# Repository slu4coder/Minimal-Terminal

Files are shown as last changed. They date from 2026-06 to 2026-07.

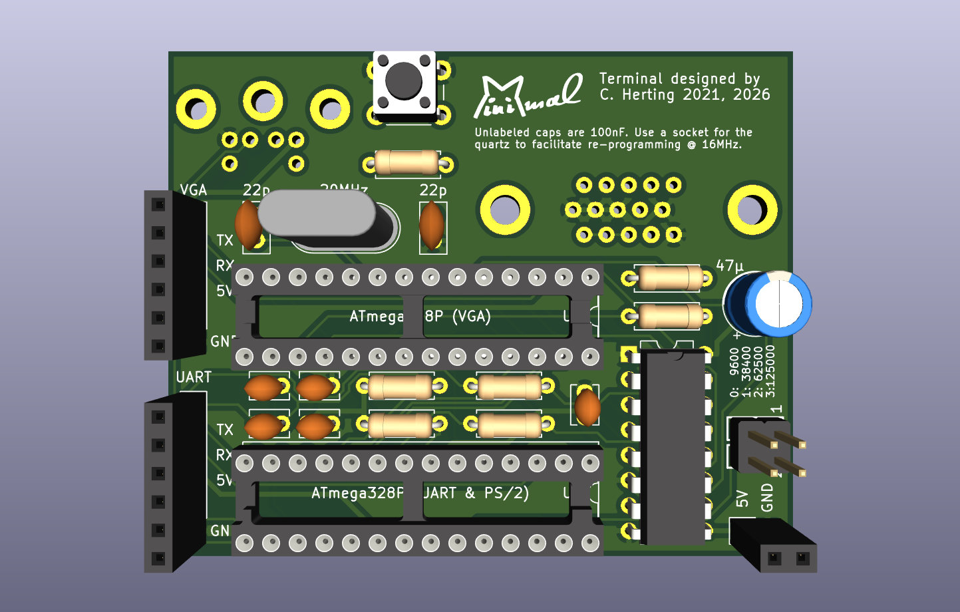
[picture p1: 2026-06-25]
Layout.jpg

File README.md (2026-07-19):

# Minimal Terminal 2026

This is my 'Minimal Serial UART Terminal' with a 50x30 character VGA display, PS2 keyboard readout (US, GER) and UART baudrates from 9600bps up to 500kbps. The design is based upon two ATmega328Ps and is described here: https://www.youtube.com/watch?v=jR-SqXLgBNo

grafik

This is a free and non-commercial project. I am in no way associated with any activies selling the 'Minimal Terminal' as a product. Any such activity represents a license violation. Individual licenses apply for hardware and software parts. Please refer to the applicable documentations for detailed licensing information. 

The Minimal Terminal is now ready to be used together with the 'Minimal UART Computer 3': https://github.com/slu4coder/Minimal-UART-Computer-3

Augusto Baffa has added support for US-international keyboard map: https://github.com/abaffa/Minimal-Terminal

I use a 20MHz crystal for a 50 x 30 characters display (default). In this setup, the following baudrates are possible: 500k, 250k, 230.4, 125k, 115.2k, 39: 62.5k, 57.6k, 38.4k,  28.8k, 19.2k, 9.6k

From these, I have imlemented the following four baudrates as "selectable via jumper":

grafik

Please note that per default the "1" and "2" values are pulled up, resulting in mode "3" or 125kbps. A jumper between GND and 5V *turns off* a value, respectively.

Optional (see source code for necessary modifications and baudrate possibilities):

o 16MHz crystal for a 40 x 30 characters display. 

o 24MHz crystal for a 60 x 30 characters display. Some users have reported that while older ICs
drive passive crystals at this frequency without problems, newer lots may need an active 24MHz oscillator.

See the Manual 'Minimal UART Computer 3', section 'Native Tool Chain / Terminal' for more information:
https://docs.google.com/document/d/1nIM-WRrVe7SzYY-DS1jcVHC4TCuIhlQ6LCHnZnEml7k/edit?usp=sharing

If you like this project and want to give something back, you can do so via PayPal. Thanks!

https://paypal.me/CarstenHerting

# Preparing the ATmega328 ICs

On a fresh ATmega328P, we set the low fuse byte from factory setting 0x62 (run on 8MHz internal oscillator) to
  
  ATmega328P ("I/O"): low fuse byte = 0xBF (use external oscillator, provide clock CLK0 on PB0)
  
  ATmega328P ("VGA"): low fuse byte = 0xF0 (use a provided external TTL clock)

1. Upload the sketch 'examples/ArduinoISP' into a spare Arduino Nano/Uno we’ll be using as a programmer.

2. Select 'Tools/Programmer/Arduino as ISP' (not ‘ArduinoISP’!).

On Windows: Open (or search for) the file: C:\Program Files (x86)\Arduino\hardware\arduino\avr\boards.txt

On Linux: Open (or search for) the file in a console with: sudo nano /usr/share/arduino/hardware/arduino/avr/boards.txt

3. We’ll hijack the configuration 'Arduino Nano' for our purpose:

Find the section: '## Arduino Nano w/ ATmega328P'. Change to: 'nano.menu.cpu.atmega328.bootloader.low_fuses=0xFF' and save the file (nano: Ctrl+O, Ctrl+X).

Close & reopen the Arduino IDE for the changes to become active.

Select target board: 'Arduino Nano', processor: 'AtMega328P'.

Connect the target's ISP to the programmer's ISP as shown below.

Select 'Tools/Burn bootloader' (takes ~5 seconds). Ignore errors for now. The fuse bytes are usually written as we’ve specified.

Upload the sketch into the TARGET with "Upload using Programmer", not the usual “Upload” or button.

Or use the serial upload connectors on the PCB with a breakout board if you've written a bootloader. Use a 16MHz crystal for programming.

PROGRAMMER (UNO/NANO)     TARGET (ATmega328P)

D13 (SCK) <-------------> Pin 19

D12 (MISO) <------------> Pin 18

D11 (MOSI) <------------> Pin 17

D10 (/RESET) <----------> Pin 1 <----- 10k ----> 5V

5V <--------------------> Pin 7

GND <-------------------> Pin 8

						  Pin 9 <----- 22p ----> GND

						  Pin 10 <---- 22p ----> GND

Pin 9/10: 16MHz crystal required for programming

o In case you write 0xF0 for external clock, the upload of the boot loader will not work,
	until you provide an external clock to IC pin 9.
  
o In case you write 0x62 the chip is running in factory setting (using its internal 8MHz oscillator at CPU clock 1MHz).

o In case you write 0xBF for CLK output on D8 (PB0, IC pin 14) verify with an LED and resistor.

o You can also upload a sketch into the ATmega328P with 'Sketch/Upload Using Programmer'.

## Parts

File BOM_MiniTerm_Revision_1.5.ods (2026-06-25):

Item | Qty | Reference(s) | Value | LibPart | Footprint
1 | 2 | C1, C2 | .1µ | Device:C_Small | Capacitor_THT:C_Disc_D3.8mm_W2.6mm_P2.50mm
2 | 1 | C3 | 47µ | Device:CP | Capacitor_THT:CP_Radial_D6.3mm_P2.50mm
3 | 3 | C4, C9, C10 | .1µ | Device:C | Capacitor_THT:C_Disc_D3.8mm_W2.6mm_P2.50mm
4 | 2 | C5, C7 | 22p | Device:C_Small | Capacitor_THT:C_Disc_D5.0mm_W2.5mm_P2.50mm
5 | 1 | J1 | UART | Connector:Conn_01x06_Female | Connector_PinSocket_2.54mm:PinSocket_1x06_P2.54mm_Vertical
6 | 1 | J2 | PS/2 Keyboard | Connector:Mini-DIN-6 | ArduinoPC:FP_MINI_DIN_6_PS2
7 | 1 | J3 | VGA DB15 HD Connector (Female) | Connector:DB15_Female_HighDensity | ArduinoPC:VGA DSUB15HD_female
8 | 1 | J4 | 5V | Connector:Conn_01x02_Female | Connector_PinSocket_2.54mm:PinSocket_1x02_P2.54mm_Vertical
9 | 1 | J5 | VGA | Connector:Conn_01x06_Female | Connector_PinSocket_2.54mm:PinSocket_1x06_P2.54mm_Vertical
10 | 1 | J6 | SPEED | Connector_Generic:Conn_02x02_Top_Bottom | ArduinoPC:PinHeader_2x02_P2.54mm_Vertical_Jumper
11 | 2 | R1, R2 | 1k | Device:R | Resistor_THT:R_Axial_DIN0207_L6.3mm_D2.5mm_P7.62mm_Horizontal
12 | 2 | R3, R4 | 10k | Device:R | Resistor_THT:R_Axial_DIN0207_L6.3mm_D2.5mm_P7.62mm_Horizontal
13 | 1 | R5 | 150 | Device:R | Resistor_THT:R_Axial_DIN0207_L6.3mm_D2.5mm_P7.62mm_Horizontal
14 | 2 | R6, R7 | 75 | Device:R | Resistor_THT:R_Axial_DIN0207_L6.3mm_D2.5mm_P7.62mm_Horizontal
15 | 1 | SW1 | SW_Push | Switch:SW_Push | Button_Switch_THT:SW_PUSH_6mm
16 | 1 | U1 | 74HC166 | ArduinoPC:74HC166 | Package_DIP:DIP-16_W7.62mm
17 | 1 | U2 | ATmega328P (VGA) | ArduinoPC:ATmega328P-PU | Package_DIP:DIP-28_W7.62mm_Socket
18 | 1 | U3 | ATmega328P (UART & PS/2) | ArduinoPC:ATmega328P-PU | Package_DIP:DIP-28_W7.62mm_Socket
19 | 1 | Y1 | 20MHz | Device:Crystal_Small | Crystal:Crystal_HC18-U_Vertical
20 | 2 |  |  | Jumper

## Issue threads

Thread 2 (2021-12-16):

Full Swing Crystal Oscillator on 24Mhz

abaffa, 2021-12-16:
Hi ,
your solution is really nice! Are you using full external clock to generate 24mhz? I could not make it work on 24mhz using the atmega oscillator circuit :(

Best,
Augusto Baffa

abaffa, 2021-12-31:
I modified to use an active oscillator for 24mhz and it's working well... also I changed the ps/2 scancodes to us-international keyboard map... check my improvements at https://github.com/abaffa/Minimal-Terminal :)

Closed 2021-12-31.

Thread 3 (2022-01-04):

80 x 25 again... but now based on Grant Searle's solution

abaffa, 2022-01-04:
Hi,
  I'm trying to port the Grant Searle's solution to your project but I'll need some time to understand the assembly code. Maybe it's more familiar to you and can help to improve the terminal http://searle.x10host.com/MonitorKeyboard/index.html

Grant Searle's projects are very popular and probably you already saw that... but it's interesting how he could generate 80x25 chars ntsc B&W with 16mhz clock. The project is quite similiar to urs (using 74x166 to serialize the video signal) and two atmegas (atmega88 to uart/ps2).

I've compared the connections from both projects and I guess it's easy to adapt the video generation code - All code is asm and compiled using Avr Studio 7 so that's how he got more processing capacity.

best regards and happy new year \o/

Augusto Baffa

Closed 2022-02-22.

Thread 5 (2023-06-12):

Uart chip inactive without keyboard attached

MRjimbob81, 2023-06-12:
Hello,

Looks like the UART/PS2 processor is in a constant wait state (or crashed) if no keyboard is attached to the PS2 port on initial startup.
This will not allow any UART traffic to pass through to the VGA processor to be displayed on screen. eg: a keyboard-less terminal.

slu4coder, 2023-06-21:
Hi,
I cannot confirm or reproduce this behavior on my hardware. Powering up the terminal without PS/2 keyboard attached leaves my Minimal Terminal running just fine and displaying received characters.

MRjimbob81, 2023-06-22:
Looks like this issue was my own stupidity. I burn'ed a forked image to the UART/PS2 processor and not the original one. Both files have the same file name...

My apologies.

Closed 2023-06-22.

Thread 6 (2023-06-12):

Uart processor drives Tx line hard blocking serial traffic

MRjimbob81, 2023-06-12:
Not a bug per say - just an observation.

The UART/PS2 processor drives the Tx line constantly at such a level that it overpowers any other Tx data on that line.
An example would be where an upstream MCU receives serial input from the PS2 keyboard, PC serial output and/or output from another serial device.

Maybe making the Tx output hi-Z when not transmitting would allow other traffic to pass through.

slu4coder, 2023-06-21:
Thanks for pointing this out. Since I am using the standard Arduino functions 'Serial.begin', 'Serial.print' etc. for this, I'd rather keep the code simple as it is. Feel free to experiment with fiddling around with the data direction register of the Arduino in between sending stuff to adapt for your needs.

Closed 2023-06-21.

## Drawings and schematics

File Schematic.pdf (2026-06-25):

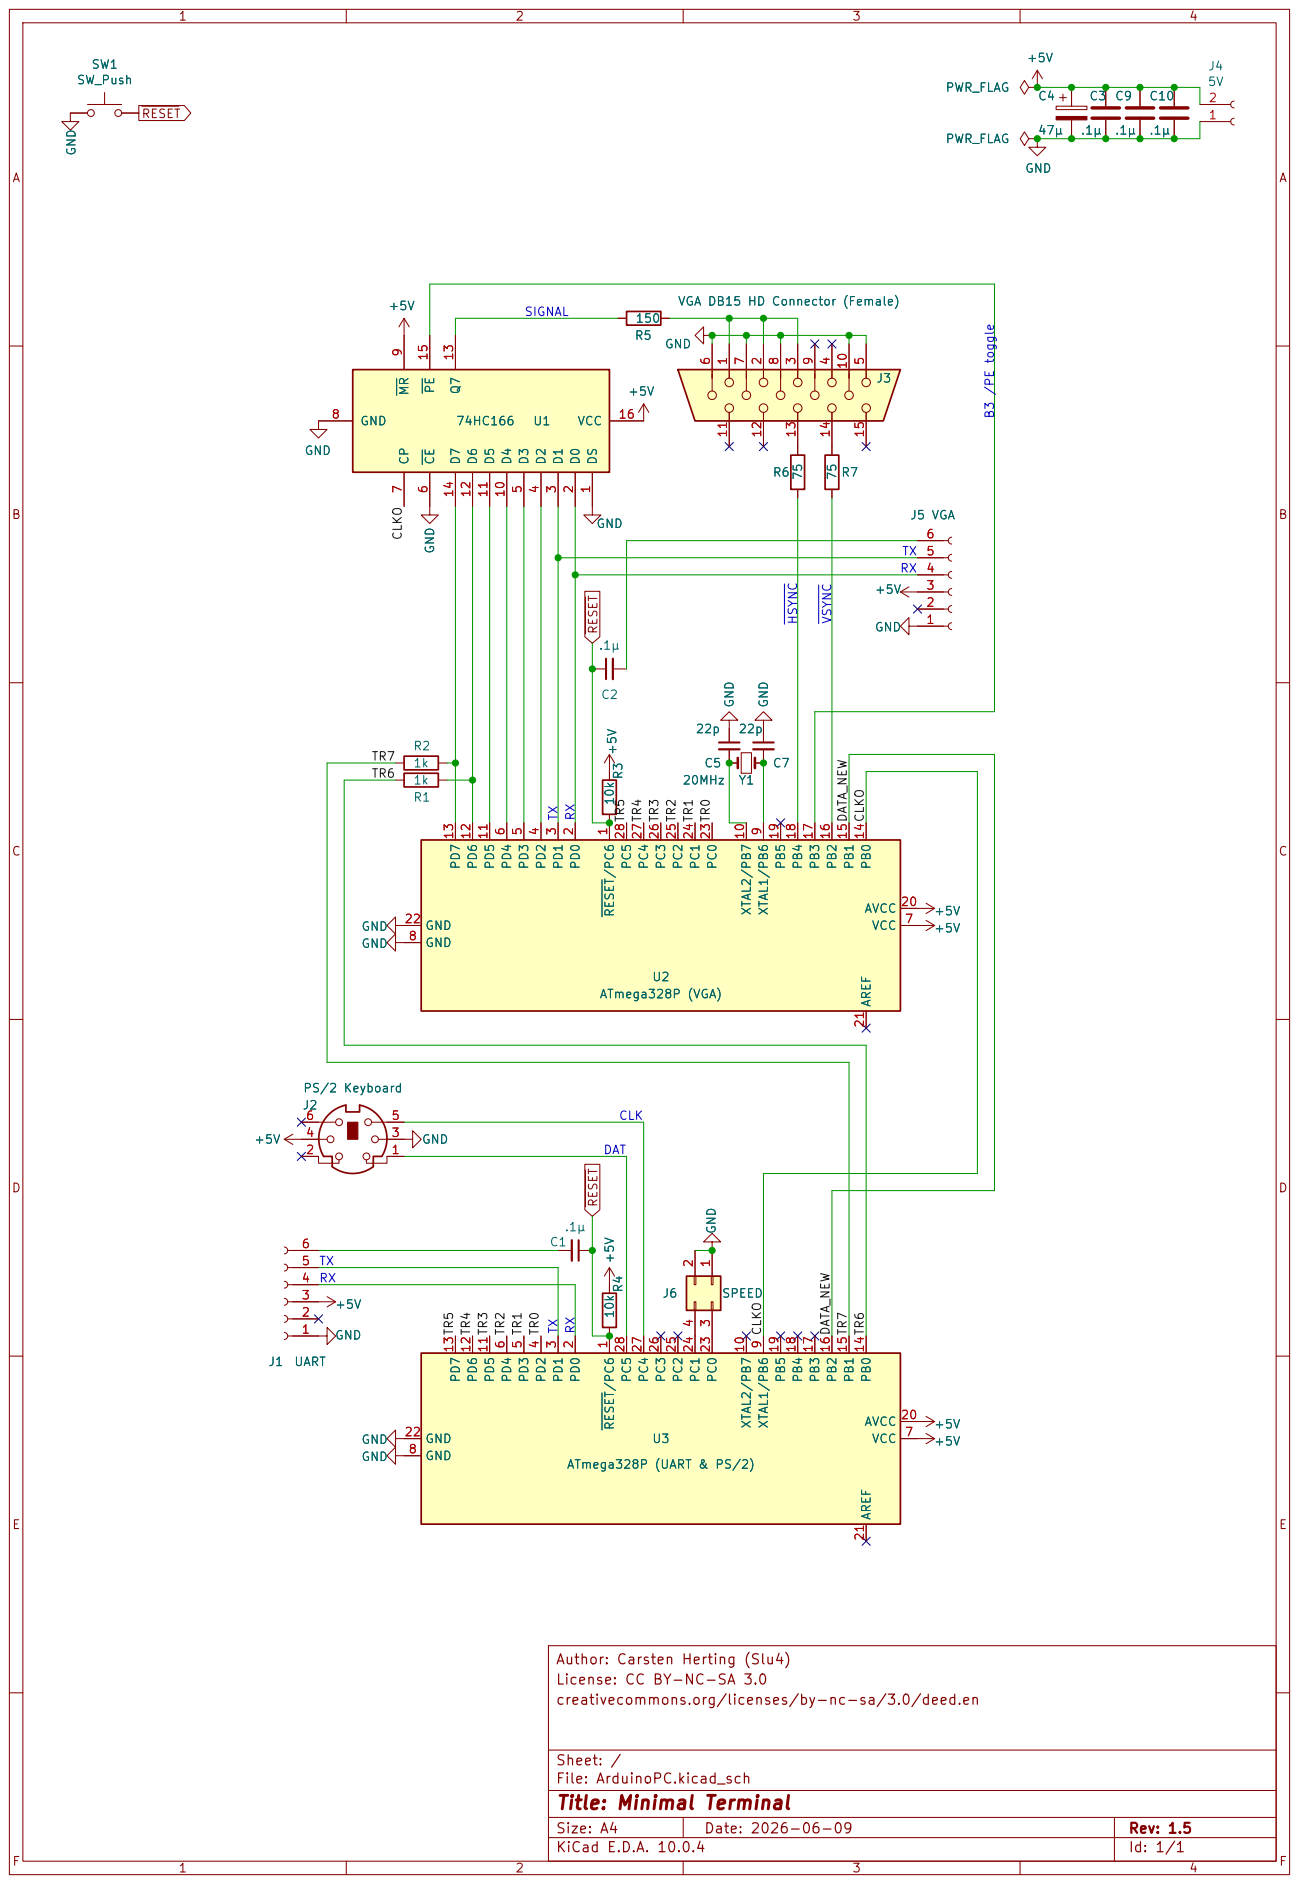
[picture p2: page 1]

VGA DB15 HD Connector (Female)

VGA DB15 HD Connector (Female) 6

License: CC BY-NC-SA 3.0
creativecommons.org/licenses/by-nc-sa/3.0/deed.en

Size: A4 | Rev: 1.5
KiCad E.D.A. 10.0.4 | Id: 1/1 | F Date: 2026-06-09

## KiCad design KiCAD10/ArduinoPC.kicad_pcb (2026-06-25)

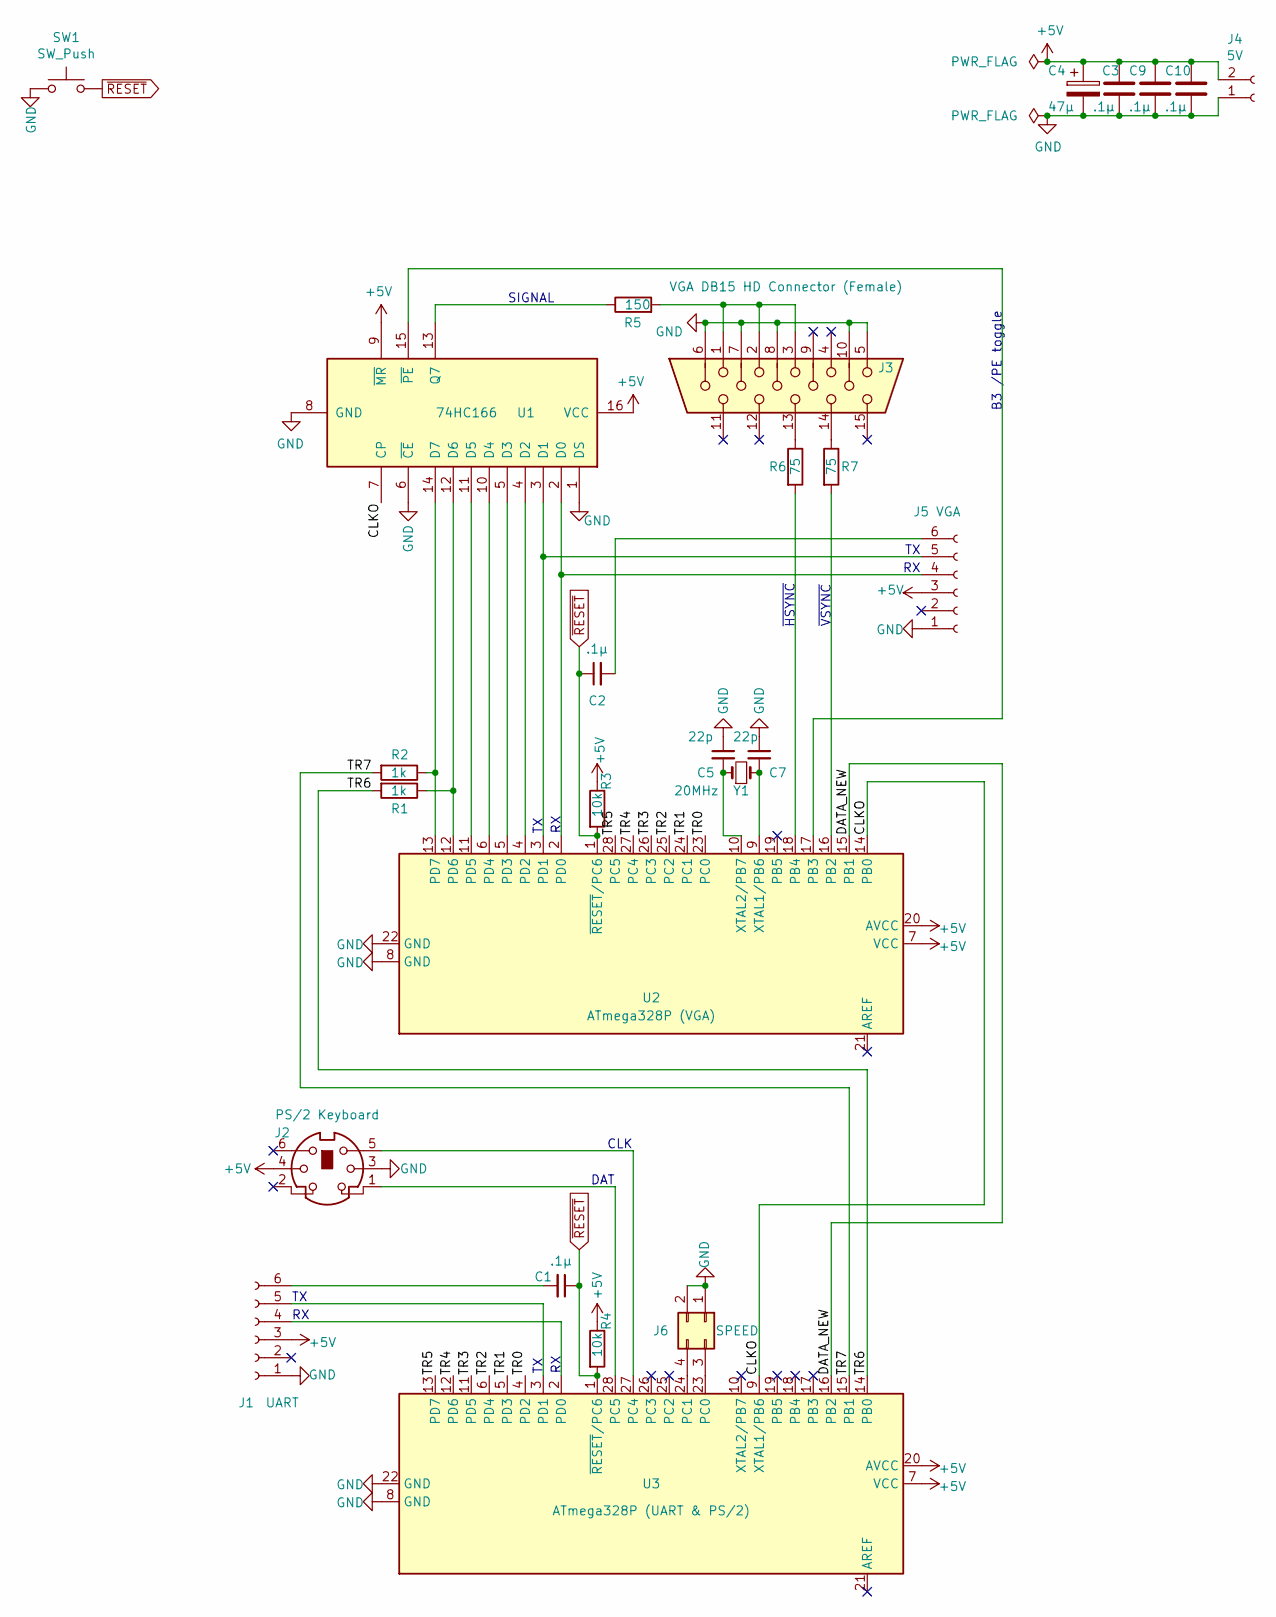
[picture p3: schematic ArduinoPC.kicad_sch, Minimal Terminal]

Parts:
C1, C2, C4, C9, C10: .1µ; C_Disc_D3.8mm_W2.6mm_P2.50mm
C3: 47µ; CP_Radial_D6.3mm_P2.50mm
C5, C7: 22p; C_Disc_D5.0mm_W2.5mm_P2.50mm
J1: UART; PinSocket_1x06_P2.54mm_Vertical
J2: PS/2 Keyboard; FP_MINI_DIN_6_PS2
J3: VGA DB15 HD Connector (Female); VGA DSUB15HD_female
J4: 5V; PinSocket_1x02_P2.54mm_Vertical
J5: VGA; PinSocket_1x06_P2.54mm_Vertical
J6: SPEED; PinHeader_2x02_P2.54mm_Vertical_Jumper
R1, R2: 1k; R_Axial_DIN0207_L6.3mm_D2.5mm_P7.62mm_Horizontal
R3, R4: 10k; R_Axial_DIN0207_L6.3mm_D2.5mm_P7.62mm_Horizontal
R5: 150; R_Axial_DIN0207_L6.3mm_D2.5mm_P7.62mm_Horizontal
R6, R7: 75; R_Axial_DIN0207_L6.3mm_D2.5mm_P7.62mm_Horizontal
SW1: SW_Push; SW_PUSH_6mm
U1: 74HC166; DIP-16_W7.62mm
U2: ATmega328P (VGA); DIP-28_W7.62mm_Socket
U3: ATmega328P (UART & PS/2); DIP-28_W7.62mm_Socket
Y1: 20MHz; Crystal_HC18-U_Vertical

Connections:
+5V: C3.1, C4.1, C9.1, C10.1, J1.3, J2.4, J4.2, J5.3, R3.1, R4.1, U1.9 (~MR), U1.16 (VCC), U2.7 (VCC), U2.20 (AVCC), U3.7 (VCC), U3.20 (AVCC)
/CLKO: U1.7 (CP), U2.14 (PB0), U3.9 (XTAL1/PB6)
/DATA_NEW: U2.15 (PB1), U3.16 (PB2)
/TR0: U2.23 (PC0), U3.4 (PD2)
/TR1: U2.24 (PC1), U3.5 (PD3)
/TR2: U2.25 (PC2), U3.6 (PD4)
/TR3: U2.26 (PC3), U3.11 (PD5)
/TR4: U2.27 (PC4), U3.12 (PD6)
/TR5: U2.28 (PC5), U3.13 (PD7)
/TR6: R1.2, U3.14 (PB0)
/TR7: R2.2, U3.15 (PB1)
GND: C3.2, C4.2, C5.1, C7.1, C9.2, C10.2, J1.1, J2.3, J3.5, J3.6, J3.7, J3.8, J3.10, J4.1, J5.1, J6.1, J6.2, SW1.1, U1.1 (DS), U1.6 (~CE), U1.8 (GND), U2.8 (GND), U2.22 (GND), U3.8 (GND), U3.22 (GND)
unnamed: C1.2, J1.6
unnamed: C2.2, J5.6
unnamed: C5.2, U2.10 (XTAL2/PB7), Y1.1
unnamed: C7.2, U2.9 (XTAL1/PB6), Y1.2
unnamed: J1.4, U3.2 (PD0)
unnamed: J1.5, U3.3 (PD1)
unnamed: J2.1, U3.28 (PC5)
unnamed: J2.5, U3.27 (PC4)
unnamed: J3.1, J3.2, J3.3, R5.2
unnamed: J3.13, R6.1
unnamed: J3.14, R7.1
unnamed: J5.4, U1.2 (D0), U2.2 (PD0)
unnamed: J5.5, U1.3 (D1), U2.3 (PD1)
unnamed: J6.3, U3.23 (PC0)
unnamed: J6.4, U3.24 (PC1)
unnamed: R1.1, U1.12 (D6), U2.12 (PD6)
unnamed: R2.1, U1.14 (D7), U2.13 (PD7)
unnamed: R5.1, U1.13 (Q7)
unnamed: R6.2, U2.18 (PB4)
unnamed: R7.2, U2.16 (PB2)
unnamed: U1.4 (D2), U2.4 (PD2)
unnamed: U1.5 (D3), U2.5 (PD3)
unnamed: U1.10 (D4), U2.6 (PD4)
unnamed: U1.11 (D5), U2.11 (PD5)
unnamed: U1.15 (~PE), U2.17 (PB3)
~RESET: C1.1, C2.1, R3.2, R4.2, SW1.2, U2.1 (~RESET/PC6), U3.1 (~RESET/PC6)

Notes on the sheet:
CLK
SIGNAL
B3 /PE toggle
~{VSYNC}
~{HSYNC}
DAT

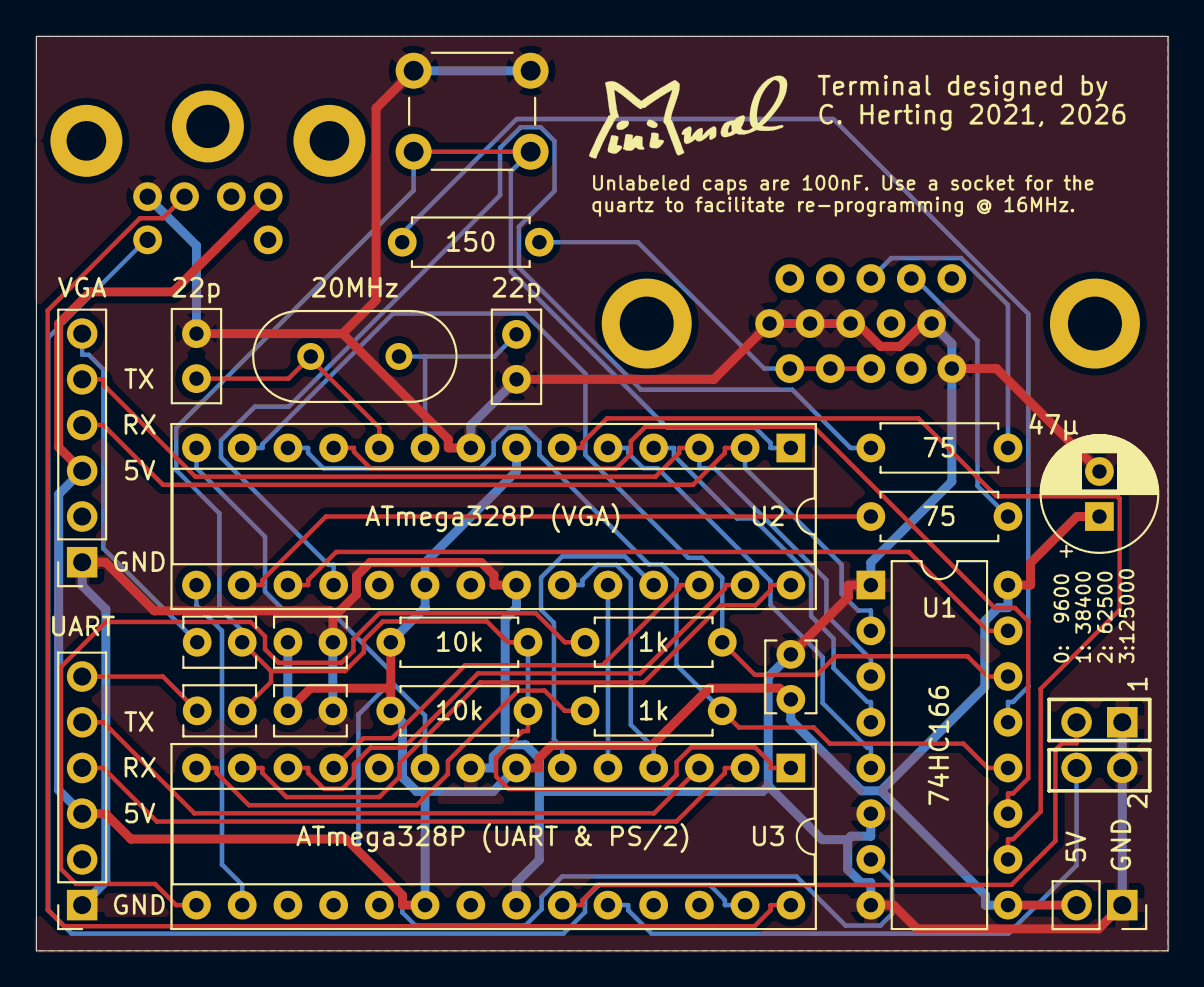
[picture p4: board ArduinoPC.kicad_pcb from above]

Board: 2 copper layers, 62.9 x 50.8 mm, 26 parts (0 on the bottom side), 38 nets.

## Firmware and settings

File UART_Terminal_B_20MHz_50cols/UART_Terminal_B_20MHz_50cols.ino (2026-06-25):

// ***************************************************************************
// *****                                                                 *****
// ***** AtMega328P UART ANSI Terminal with 50x30 Character VGA and PS/2 *****
// *****                                                                 *****
// *****        written by Carsten Herting 16.08.2025 Version 2.3        *****
// *****                                                                 *****
// ***************************************************************************
// Set AtMega328P FuseA from 0xFF to 0xBF to output system clock CLKO on PB0
// Pin C0-5: terminal input bits 0-5
// Pin D0-7: parallel pixel output to 74166, in between: D6-7 terminal input bits 6-7
// Pin B0:   CLKO ATmega328 system clock output (program fuse byte to 0xBF)
// Pin B1:   DATA_NEW input handshake
// Pin B2:   /VSYNC VGA (timer1, every 1/60s, could also be done)
// Pin B3:   /PE low pulse (by hand inside ISR for 74166 /PE pixel shift register sync parallel load)
// Pin B4:   /HSYNC VGA (by hand inside ISR, every 32µs)
// Pin B5:   DATA_ACK output handshake
// See license at the end of this file.

#define WIDTH     50              // 20MHz crystal required
#define HEIGHT    30

char row = 0, col = 0;            // current cursor position in terminal window
char hideCursor = 0;              // cursor can be switched off by CSI
volatile int vline = 0;           // current vertical position of pixel video output
volatile byte vram[HEIGHT][WIDTH];// array of VideoRAM
volatile char start = 0;          // start line of the VideoRAM (thus avoiding moving data while scrolling)
volatile int frames = 0;          // 1/60s frame counter for cursor blinking
volatile byte regout = 0;         // index of current output position in queue
volatile byte regin = 0;          // index of current input position in queue
volatile byte reg[256];           // ring buffer data of keyboard input register

const volatile byte __attribute__ ((aligned (256))) charset[8][256] PROGMEM =
{
  0x00,0x00,0x00,0x00,0x00,0x00,0x00,0x00,0x00,0x00,0x00,0x00,0x00,0x00,0x00,0x00,0x00,0x00,0x00,0x00,0x00,0x00,0x00,0x00,0x00,0x00,0x00,0x00,0x00,0x00,0x03,0xC0,0x00,0x18,0x66,0x66,0x18,0x62,0x3C,0x06,0x0C,0x30,0x00,0x00,0x00,0x00,0x00,0x00,0x3C,0x18,0x3C,0x3C,0x06,0x7E,0x3C,0x7E,0x3C,0x3C,0x00,0x00,0x0E,0x00,0x70,0x3C,0x3C,0x18,0x7C,0x3C,0x78,0x7E,0x7E,0x3C,0x66,0x3C,0x1E,0x66,0x60,0x63,0x66,0x3C,0x7C,0x3C,0x7C,0x3C,0x7E,0x66,0x66,0x63,0x66,0x66,0x7E,0x3C,0x00,0x3C,0x00,0x00,0x3C,0x00,0x00,0x00,0x00,0x00,0x00,0x00,0x00,0x00,0x00,0x00,0x00,0x00,0x00,0x00,0x00,0x00,0x00,0x00,0x00,0x00,0x00,0x00,0x00,0x00,0x00,0x0E,0x18,0x70,0x00,0x00,0x00,0x00,0x00,0x18,0x18,0x18,0x18,0x18,0x18,0x00,0x00,0x00,0x18,0x18,0xFF,0xFF,0x01,0x80,0x0F,0xF0,0xFF,0x00,0x0F,0xF0,0xFF,0x00,0x0F,0xF0,0xFF,0x00,0x0F,0xF0,0xFF,0xE7,0x99,0x99,0xE7,0x9D,0xC3,0xF9,0xF3,0xCF,0xFF,0xFF,0xFF,0xFF,0xFF,0xFF,0xC3,0xE7,0xC3,0xC3,0xF9,0x81,0xC3,0x81,0xC3,0xC3,0xFF,0xFF,0xF1,0xFF,0x8F,0xC3,0xC3,0xE7,0x83,0xC3,0x87,0x81,0x81,0xC3,0x99,0xC3,0xE1,0x99,0x9F,0x9C,0x99,0xC3,0x83,0xC3,0x83,0xC3,0x81,0x99,0x99,0x9C,0x99,0x99,0x81,0xC3,0xFF,0xC3,0xFF,0xFF,0xC3,0xFF,0xFF,0xFF,0xFF,0xFF,0xFF,0xFF,0xFF,0xFF,0xFF,0xFF,0xFF,0xFF,0xFF,0xFF,0xFF,0xFF,0xFF,0xFF,0xFF,0xFF,0xFF,0xFF,0xFF,0xFF,0xFF,0xF1,0xE7,0x8F,0xFF,0xFF,
  0x00,0x00,0x00,0x00,0x00,0x00,0x00,0x00,0x00,0x00,0x00,0x00,0x00,0x00,0x00,0x00,0x00,0x00,0x00,0x00,0x00,0x00,0x00,0x00,0x00,0x00,0x00,0x00,0x00,0x00,0x07,0xE0,0x00,0x18,0x66,0x66,0x3E,0x66,0x66,0x0C,0x18,0x18,0x66,0x18,0x00,0x00,0x00,0x03,0x66,0x18,0x66,0x66,0x0E,0x60,0x66,0x66,0x66,0x66,0x00,0x00,0x18,0x00,0x18,0x66,0x66,0x3C,0x66,0x66,0x6C,0x60,0x60,0x66,0x66,0x18,0x0C,0x6C,0x60,0x77,0x76,0x66,0x66,0x66,0x66,0x66,0x18,0x66,0x66,0x63,0x66,0x66,0x06,0x30,0x60,0x0C,0x18,0x00,0x66,0x00,0x60,0x00,0x06,0x00,0x0E,0x00,0x60,0x18,0x06,0x60,0x38,0x00,0x00,0x00,0x00,0x00,0x00,0x00,0x18,0x00,0x00,0x00,0x00,0x00,0x00,0x18,0x18,0x18,0x00,0x10,0x00,0x00,0x00,0x18,0x18,0x18,0x18,0x18,0x18,0x00,0x00,0x00,0x18,0x18,0x7F,0xFE,0x03,0xC0,0x0F,0xF0,0xFF,0x00,0x0F,0xF0,0xFF,0x00,0x0F,0xF0,0xFF,0x00,0x0F,0xF0,0xFF,0xE7,0x99,0x99,0xC1,0x99,0x99,0xF3,0xE7,0xE7,0x99,0xE7,0xFF,0xFF,0xFF,0xFC,0x99,0xE7,0x99,0x99,0xF1,0x9F,0x99,0x99,0x99,0x99,0xFF,0xFF,0xE7,0xFF,0xE7,0x99,0x99,0xC3,0x99,0x99,0x93,0x9F,0x9F,0x99,0x99,0xE7,0xF3,0x93,0x9F,0x88,0x89,0x99,0x99,0x99,0x99,0x99,0xE7,0x99,0x99,0x9C,0x99,0x99,0xF9,0xCF,0x9F,0xF3,0xE7,0xFF,0x99,0xFF,0x9F,0xFF,0xF9,0xFF,0xF1,0xFF,0x9F,0xE7,0xF9,0x9F,0xC7,0xFF,0xFF,0xFF,0xFF,0xFF,0xFF,0xFF,0xE7,0xFF,0xFF,0xFF,0xFF,0xFF,0xFF,0xE7,0xE7,0xE7,0xFF,0xEF,
  0x00,0x00,0x00,0x00,0x00,0x00,0x00,0x00,0x00,0x00,0x00,0x00,0x00,0x00,0x00,0x00,0x00,0x00,0x00,0x00,0x00,0x00,0x00,0x00,0x00,0x00,0x00,0x00,0x00,0x00,0x0E,0x70,0x00,0x18,0x66,0xFF,0x60,0x0C,0x3C,0x18,0x30,0x0C,0x3C,0x18,0x00,0x00,0x00,0x06,0x6E,0x38,0x06,0x06,0x1E,0x7C,0x60,0x0C,0x66,0x66,0x18,0x18,0x30,0x7E,0x0C,0x06,0x6E,0x66,0x66,0x60,0x66,0x60,0x60,0x60,0x66,0x18,0x0C,0x78,0x60,0x7F,0x7E,0x66,0x66,0x66,0x66,0x60,0x18,0x66,0x66,0x63,0x3C,0x66,0x0C,0x30,0x30,0x0C,0x3C,0x00,0x6E,0x3C,0x60,0x3C,0x06,0x3C,0x18,0x3E,0x60,0x00,0x00,0x60,0x18,0x66,0x7C,0x3C,0x7C,0x3E,0x7C,0x3E,0x7E,0x66,0x66,0x63,0x66,0x66,0x7E,0x18,0x18,0x18,0x00,0x30,0x00,0x00,0x00,0x18,0x18,0x18,0x18,0x18,0x18,0x00,0x00,0x00,0x1C,0x38,0x3F,0xFC,0x07,0xE0,0x0F,0xF0,0xFF,0x00,0x0F,0xF0,0xFF,0x00,0x0F,0xF0,0xFF,0x00,0x0F,0xF0,0xFF,0xE7,0x99,0x00,0x9F,0xF3,0xC3,0xE7,0xCF,0xF3,0xC3,0xE7,0xFF,0xFF,0xFF,0xF9,0x91,0xC7,0xF9,0xF9,0xE1,0x83,0x9F,0xF3,0x99,0x99,0xE7,0xE7,0xCF,0x81,0xF3,0xF9,0x91,0x99,0x99,0x9F,0x99,0x9F,0x9F,0x9F,0x99,0xE7,0xF3,0x87,0x9F,0x80,0x81,0x99,0x99,0x99,0x99,0x9F,0xE7,0x99,0x99,0x9C,0xC3,0x99,0xF3,0xCF,0xCF,0xF3,0xC3,0xFF,0x91,0xC3,0x9F,0xC3,0xF9,0xC3,0xE7,0xC1,0x9F,0xFF,0xFF,0x9F,0xE7,0x99,0x83,0xC3,0x83,0xC1,0x83,0xC1,0x81,0x99,0x99,0x9C,0x99,0x99,0x81,0xE7,0xE7,0xE7,0xFF,0xCF,
  0x00,0x00,0x00,0x00,0x00,0x00,0x00,0x00,0x00,0x00,0x00,0x00,0x00,0x00,0x00,0x00,0x00,0x00,0x00,0x00,0x00,0x00,0x00,0x00,0x00,0x00,0x00,0x00,0x00,0x00,0x1C,0x38,0x00,0x18,0x00,0x66,0x3C,0x18,0x38,0x00,0x30,0x0C,0xFF,0x7E,0x00,0x7E,0x00,0x0C,0x76,0x18,0x0C,0x1C,0x66,0x06,0x7C,0x18,0x3C,0x3E,0x00,0x00,0x60,0x00,0x06,0x0C,0x6E,0x7E,0x7C,0x60,0x66,0x78,0x78,0x6E,0x7E,0x18,0x0C,0x70,0x60,0x6B,0x7E,0x66,0x7C,0x66,0x7C,0x3C,0x18,0x66,0x66,0x6B,0x18,0x3C,0x18,0x30,0x18,0x0C,0x7E,0x00,0x6E,0x06,0x7C,0x60,0x3E,0x66,0x3E,0x66,0x7C,0x38,0x06,0x6C,0x18,0x7F,0x66,0x66,0x66,0x66,0x66,0x60,0x18,0x66,0x66,0x6B,0x3C,0x66,0x0C,0x70,0x18,0x0E,0x3B,0x7F,0x1F,0xFF,0xF8,0x1F,0xFF,0xF8,0x1F,0xFF,0xF8,0xFF,0x07,0xE0,0x0F,0xF0,0x1F,0xF8,0x0F,0xF0,0x0F,0xF0,0xFF,0x00,0x0F,0xF0,0xFF,0x00,0x0F,0xF0,0xFF,0x00,0x0F,0xF0,0xFF,0xE7,0xFF,0x99,0xC3,0xE7,0xC7,0xFF,0xCF,0xF3,0x00,0x81,0xFF,0x81,0xFF,0xF3,0x89,0xE7,0xF3,0xE3,0x99,0xF9,0x83,0xE7,0xC3,0xC1,0xFF,0xFF,0x9F,0xFF,0xF9,0xF3,0x91,0x81,0x83,0x9F,0x99,0x87,0x87,0x91,0x81,0xE7,0xF3,0x8F,0x9F,0x94,0x81,0x99,0x83,0x99,0x83,0xC3,0xE7,0x99,0x99,0x94,0xE7,0xC3,0xE7,0xCF,0xE7,0xF3,0x81,0xFF,0x91,0xF9,0x83,0x9F,0xC1,0x99,0xC1,0x99,0x83,0xC7,0xF9,0x93,0xE7,0x80,0x99,0x99,0x99,0x99,0x99,0x9F,0xE7,0x99,0x99,0x94,0xC3,0x99,0xF3,0x8F,0xE7,0xF1,0xC4,0x80,
  0x00,0x00,0x00,0x00,0x00,0x00,0x00,0x00,0x00,0x00,0x00,0x00,0x00,0x00,0x00,0x00,0x00,0x00,0x00,0x00,0x00,0x00,0x00,0x00,0x00,0x00,0x00,0x00,0x00,0x00,0x38,0x1C,0x00,0x00,0x00,0xFF,0x06,0x30,0x67,0x00,0x30,0x0C,0x3C,0x18,0x00,0x00,0x00,0x18,0x66,0x18,0x30,0x06,0x7F,0x06,0x66,0x18,0x66,0x06,0x00,0x00,0x30,0x7E,0x0C,0x18,0x60,0x66,0x66,0x60,0x66,0x60,0x60,0x66,0x66,0x18,0x0C,0x78,0x60,0x63,0x6E,0x66,0x60,0x66,0x78,0x06,0x18,0x66,0x66,0x7F,0x3C,0x18,0x30,0x30,0x0C,0x0C,0x18,0x00,0x60,0x3E,0x66,0x60,0x66,0x7E,0x18,0x66,0x66,0x18,0x06,0x78,0x18,0x7F,0x66,0x66,0x66,0x66,0x60,0x3C,0x18,0x66,0x66,0x7F,0x18,0x66,0x18,0x18,0x18,0x18,0x6E,0x7F,0x1F,0xFF,0xF8,0x1F,0xFF,0xF8,0x1F,0xFF,0xF8,0xFF,0x0F,0xF0,0x07,0xE0,0x0F,0xF0,0x1F,0xF8,0x00,0x00,0x00,0x0F,0x0F,0x0F,0x0F,0xF0,0xF0,0xF0,0xF0,0xFF,0xFF,0xFF,0xFF,0xFF,0xFF,0x00,0xF9,0xCF,0x98,0xFF,0xCF,0xF3,0xC3,0xE7,0xFF,0xFF,0xFF,0xE7,0x99,0xE7,0xCF,0xF9,0x80,0xF9,0x99,0xE7,0x99,0xF9,0xFF,0xFF,0xCF,0x81,0xF3,0xE7,0x9F,0x99,0x99,0x9F,0x99,0x9F,0x9F,0x99,0x99,0xE7,0xF3,0x87,0x9F,0x9C,0x91,0x99,0x9F,0x99,0x87,0xF9,0xE7,0x99,0x99,0x80,0xC3,0xE7,0xCF,0xCF,0xF3,0xF3,0xE7,0xFF,0x9F,0xC1,0x99,0x9F,0x99,0x81,0xE7,0x99,0x99,0xE7,0xF9,0x87,0xE7,0x80,0x99,0x99,0x99,0x99,0x9F,0xC3,0xE7,0x99,0x99,0x80,0xE7,0x99,0xE7,0xE7,0xE7,0xE7,0x91,0x80,
  0x00,0x00,0x00,0x00,0x00,0x00,0x00,0x00,0x00,0x00,0x00,0x00,0x00,0x00,0x00,0x00,0x00,0x00,0x00,0x00,0x00,0x00,0x00,0x00,0x00,0x00,0x00,0x00,0x00,0x00,0x70,0x0E,0x00,0x00,0x00,0x66,0x7C,0x66,0x66,0x00,0x18,0x18,0x66,0x18,0x18,0x00,0x18,0x30,0x66,0x18,0x60,0x66,0x06,0x66,0x66,0x18,0x66,0x66,0x18,0x18,0x18,0x00,0x18,0x00,0x66,0x66,0x66,0x66,0x6C,0x60,0x60,0x66,0x66,0x18,0x6C,0x6C,0x60,0x63,0x66,0x66,0x60,0x3C,0x6C,0x66,0x18,0x66,0x3C,0x77,0x66,0x18,0x60,0x30,0x06,0x0C,0x18,0x00,0x66,0x66,0x66,0x60,0x66,0x60,0x18,0x3E,0x66,0x18,0x06,0x6C,0x18,0x6B,0x66,0x66,0x7C,0x3E,0x60,0x06,0x18,0x66,0x3C,0x3E,0x3C,0x3E,0x30,0x18,0x18,0x18,0x00,0x30,0x18,0x18,0x18,0x18,0x18,0x18,0x00,0x00,0x00,0x00,0x1C,0x38,0x00,0x00,0x07,0xE0,0x3F,0xFC,0x00,0x00,0x00,0x0F,0x0F,0x0F,0x0F,0xF0,0xF0,0xF0,0xF0,0xFF,0xFF,0xFF,0xFF,0xFF,0xFF,0x99,0x83,0x99,0x99,0xFF,0xE7,0xE7,0x99,0xE7,0xE7,0xFF,0xE7,0xCF,0x99,0xE7,0x9F,0x99,0xF9,0x99,0x99,0xE7,0x99,0x99,0xE7,0xE7,0xE7,0xFF,0xE7,0xFF,0x99,0x99,0x99,0x99,0x93,0x9F,0x9F,0x99,0x99,0xE7,0x93,0x93,0x9F,0x9C,0x99,0x99,0x9F,0xC3,0x93,0x99,0xE7,0x99,0xC3,0x88,0x99,0xE7,0x9F,0xCF,0xF9,0xF3,0xE7,0xFF,0x99,0x99,0x99,0x9F,0x99,0x9F,0xE7,0xC1,0x99,0xE7,0xF9,0x93,0xE7,0x94,0x99,0x99,0x83,0xC1,0x9F,0xF9,0xE7,0x99,0xC3,0xC1,0xC3,0xC1,0xCF,0xE7,0xE7,0xE7,0xFF,0xCF,
  0x00,0x00,0x00,0x00,0x00,0x00,0x00,0x00,0x00,0x00,0x00,0x00,0x00,0x00,0x00,0x00,0x00,0x00,0x00,0x00,0x00,0x00,0x00,0x00,0x00,0x00,0x00,0x00,0x00,0x00,0xE0,0x07,0x00,0x18,0x00,0x66,0x18,0x46,0x3F,0x00,0x0C,0x30,0x00,0x00,0x18,0x00,0x18,0x60,0x3C,0x7E,0x7E,0x3C,0x06,0x3C,0x3C,0x18,0x3C,0x3C,0x00,0x18,0x0E,0x00,0x70,0x18,0x3C,0x66,0x7C,0x3C,0x78,0x7E,0x60,0x3C,0x66,0x3C,0x38,0x66,0x7E,0x63,0x66,0x3C,0x60,0x0E,0x66,0x3C,0x18,0x3C,0x18,0x63,0x66,0x18,0x7E,0x3C,0x03,0x3C,0x18,0xFF,0x3C,0x3E,0x7C,0x3C,0x3E,0x3C,0x18,0x06,0x66,0x3C,0x06,0x66,0x3C,0x63,0x66,0x3C,0x60,0x06,0x60,0x7C,0x0E,0x3E,0x18,0x36,0x66,0x0C,0x7E,0x0E,0x18,0x70,0x00,0x10,0x18,0x18,0x18,0x18,0x18,0x18,0x00,0x00,0x00,0x00,0x18,0x18,0x00,0x00,0x03,0xC0,0x7F,0xFE,0x00,0x00,0x00,0x0F,0x0F,0x0F,0x0F,0xF0,0xF0,0xF0,0xF0,0xFF,0xFF,0xFF,0xFF,0xE7,0xFF,0x99,0xE7,0xB9,0xC0,0xFF,0xF3,0xCF,0xFF,0xFF,0xE7,0xFF,0xE7,0x9F,0xC3,0x81,0x81,0xC3,0xF9,0xC3,0xC3,0xE7,0xC3,0xC3,0xFF,0xE7,0xF1,0xFF,0x8F,0xE7,0xC3,0x99,0x83,0xC3,0x87,0x81,0x9F,0xC3,0x99,0xC3,0xC7,0x99,0x81,0x9C,0x99,0xC3,0x9F,0xF1,0x99,0xC3,0xE7,0xC3,0xE7,0x9C,0x99,0xE7,0x81,0xC3,0xFC,0xC3,0xE7,0x00,0xC3,0xC1,0x83,0xC3,0xC1,0xC3,0xE7,0xF9,0x99,0xC3,0xF9,0x99,0xC3,0x9C,0x99,0xC3,0x9F,0xF9,0x9F,0x83,0xF1,0xC1,0xE7,0xC9,0x99,0xF3,0x81,0xF1,0xE7,0x8F,0xFF,0xEF,
  0x00,0x00,0x00,0x00,0x00,0x00,0x00,0x00,0x00,0x00,0x00,0x00,0x00,0x00,0x00,0x00,0x00,0x00,0x00,0x00,0x00,0x00,0x00,0x00,0x00,0x00,0x00,0x00,0x00,0x00,0xC0,0x03,0x00,0x00,0x00,0x00,0x00,0x00,0x00,0x00,0x00,0x00,0x00,0x00,0x30,0x00,0x00,0x00,0x00,0x00,0x00,0x00,0x00,0x00,0x00,0x00,0x00,0x00,0x00,0x30,0x00,0x00,0x00,0x00,0x00,0x00,0x00,0x00,0x00,0x00,0x00,0x00,0x00,0x00,0x00,0x00,0x00,0x00,0x00,0x00,0x00,0x00,0x00,0x00,0x00,0x00,0x00,0x00,0x00,0x00,0x00,0x00,0x00,0x00,0x18,0xFF,0x00,0x00,0x00,0x00,0x00,0x00,0x00,0x7C,0x00,0x00,0x3C,0x00,0x00,0x00,0x00,0x00,0x60,0x06,0x00,0x00,0x00,0x00,0x00,0x00,0x00,0x78,0x00,0x00,0x18,0x00,0x00,0x00,0x18,0x18,0x18,0x18,0x18,0x18,0x00,0x00,0x00,0x00,0x18,0x18,0x00,0x00,0x01,0x80,0xFF,0xFF,0x00,0x00,0x00,0x0F,0x0F,0x0F,0x0F,0xF0,0xF0,0xF0,0xF0,0xFF,0xFF,0xFF,0xFF,0xFF,0xFF,0xFF,0xFF,0xFF,0xFF,0xFF,0xFF,0xFF,0xFF,0xFF,0xCF,0xFF,0xFF,0xFF,0xFF,0xFF,0xFF,0xFF,0xFF,0xFF,0xFF,0xFF,0xFF,0xFF,0xFF,0xCF,0xFF,0xFF,0xFF,0xFF,0xFF,0xFF,0xFF,0xFF,0xFF,0xFF,0xFF,0xFF,0xFF,0xFF,0xFF,0xFF,0xFF,0xFF,0xFF,0xFF,0xFF,0xFF,0xFF,0xFF,0xFF,0xFF,0xFF,0xFF,0xFF,0xFF,0xFF,0xFF,0xFF,0xFF,0xE7,0x00,0xFF,0xFF,0xFF,0xFF,0xFF,0xFF,0xFF,0x83,0xFF,0xFF,0xC3,0xFF,0xFF,0xFF,0xFF,0xFF,0x9F,0xF9,0xFF,0xFF,0xFF,0xFF,0xFF,0xFF,0xFF,0x87,0xFF,0xFF,0xE7,0xFF,0xFF,0xFF,
};

void setup()
{
  noInterrupts();                   // disable interrupts before messing around with timer registers

  DDRC  = 0b00000000;               // PORTC is always input
  PORTC = 0b00000000;
  DDRD  = 0b11111111;               // PORTD is always output
  PORTD = 0b00000000;
  DDRB  = 0b00111100;               // B0-1: terminal input bits 0-1, B2: VSYNC (timer1), B3: 74165 /PL (timer2 or by hand???), B4: HSync by hand inside ISR
  PORTB = 0b00011000;               // HSYNC=1, /PE=1

  GTCCR = 0b10000011;               // set TSM, PSRSYNC und PSRASY to correlate all 3 timers

  // *****************************
  // ***** Timer0: VGA HSYNC *****
  // *****************************
  TCNT0  = 36;                       // align VSYNC and HSYNC pulses
  TCCR0A = (1 << WGM01) | (0 << WGM00);   // mode 2: Clear Timer on Compare Match (CTC)
  TCCR0B = (0 << WGM02) | (0 << CS02) | (1 << CS01) | (0 << CS00); // x8 prescaler -> 0.5µs
  OCR0A  = 79;                      // 60cols (24MHz): 95, 50cols (20MHz): 79, 40cols (16MHz): 63, compare match register A (TOP) -> 32µs
  TIMSK0 = (1 << OCIE0A);           // output Compare Match A Interrupt Enable (not working: TOIE1 with ISR TIMER0_TOIE1_vect because it is already defined by timing functions)

  // *****************************
  // ***** Timer1: VGA VSYNC *****
  // *****************************
  TCNT1  = 0;
  TCCR1A = (1 << COM1B1) | (1 << COM1B0) | (1 << WGM11) | (1 << WGM10); // mode 15 (Fast PWM), set OC1B on Compare Match, clear OC1B at BOTTOM, controlling OC1B pin 10
  TCCR1B = (1 << WGM13) | (1 << WGM12) | (1 << CS12) | (0 << CS11) | (1 << CS10); // x 1024 prescaler -> 64µs
  OCR1A  = 324;                     // 60cols (24MHz): 389, 50cols (20MHz): 324, 40cols (16MHz): 259, compare match register A (TOP) -> 16.64ms
  OCR1B  = 0;                       // compare match register B -> 64µs
  TIMSK1 = (1 << TOIE1);            // enable timer overflow interrupt setting vlines = 0

  // ************************************************
  // ***** Timer2: only used for jitter control *****
  // ************************************************
  TCNT2  = 0;
  TCCR2A = (0<<COM2A1) | (0<<COM2A0) | (1<<WGM21) | (1<<WGM20); // mode 7: Fast PWM, COM2A0=0: normal port HIGH, COM2A0=1: Toggle OC2A pin 11 on Compare Match
  TCCR2B = (1<<WGM22) | (0<<CS22) | (0<<CS21) | (1<<CS20) ;     // set x0 prescaler -> 62.5ns;
  OCR2A  = 7;                       // compare match register A (TOP) -> 250ns
  TIMSK2 = 0;                       // no interrupts here

  GTCCR = 0;                        // clear TSM => all timers start synchronously
  interrupts();

  UCSR0B = 0;                       // brute-force the USART off just in case...

  for (int j=0; j<HEIGHT; j++) for (int i=0; i<WIDTH; i++) vram[j][i] = ' ';
}

void loop()
{  
  if ((frames & 63) == 32 && col < WIDTH && hideCursor == 0) vram[row][col] |= 0b10000000;
  else if ((frames & 63) == 0 && col < WIDTH) vram[row][col] &= 0b01111111;

  if (regout != regin)                            // was a character received
  {
    if (col < WIDTH) vram[row][col] &= 0b01111111; // restore character beneath the cursor BEFORE a possible scrolling happens
    do ProcessChar(reg[regout++]); while (regout != regin); // process the character
  }
}

int main() { setup(); while (true) loop(); }      // enforce main() loop w/o serial handler

ISR(TIMER1_OVF_vect) { vline = 0; frames++; }     // timer1 overflow interrupt resets vline at HSYNC
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

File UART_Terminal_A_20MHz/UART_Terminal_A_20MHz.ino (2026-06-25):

/**************************************************************************************
  *****                                                                           *****
  ***** ATmega328P UART & PS/2 Terminal Interface written by Carsten Herting 2021 *****
  *****                 Version 2.3 (original release: 02.06.2021)                *****
  ***** 21.08.2025: Added more baudrate options for 24/20/16MHz crystals          *****
  ***** 25.06.2026: Use default 20MHz crystal for use with Minimal UART CPU 3     *****
  *****                                                                           *****                                                                           
  *************************************************************************************
  This Atmega328P reads serial data from it's UART RX and transfers it to the 2nd
  ATmega328P handling VGA. PS/2 data is converted into ASCII and sent via UART TX.
  Set the fuse byte from 0xFF to 0xF0 to use an external TTL clock (provided by B).
  C0-C3: UART SPEED SCALER
  C4: PS/2 clock input, triggers a pin change interrupt
  C5: PS/2 dtat input, sampled at the rising edge of the PS/2 clock
  D0,1: UART RX, TX
  D2-7: bits 0-5 of transfer output to C0-5
  B0,1: bits 6-7 of transfer output to D6-7 via 1k resistors
  B2: DATA_NEW output to B0 input of 2nd µC
  See license at the end of this file.
*/

volatile byte ps2_scan = 0; // holds valid PS/2 scancode (set this to 0 after processing!)

const byte LookupScanToASCII[4 * 128] PROGMEM = // lookup table (in: PS/2 scancode, out: ASCII code)
{ 
/*
  0,0,0,0,0,0,0,0,          0,0,0,0,0,0,94,0,           0,0,0,0,0,113,49,0,         0,0,121,115,97,119,50,0,     // plain key
  0,99,120,100,101,52,51,0, 0,32,118,102,116,114,53,0,  0,110,98,104,103,122,54,0,  0,0,109,106,117,55,56,0,
  0,44,107,105,111,48,57,0, 0,46,45,108,0,112,0,0,      0,0,0,0,0,96,0,0,           0,0,10,43,0,35,0,0,
  0,60,0,0,0,0,8,0,         0,0,0,0,0,0,0,0,            0,127,0,0,0,0,27,0,         0,0,0,0,0,0,0,0,
  
  0,0,0,0,0,0,0,0,          0,0,0,0,0,0,248,0,          0,0,0,0,0,81,33,0,          0,0,89,83,65,87,34,0,        // with SHIFT
  0,67,88,68,69,36,0,0,     0,0,86,70,84,82,37,0,       0,78,66,72,71,90,38,0,      0,0,77,74,85,47,40,0,
  0,59,75,73,79,61,41,0,    0,58,95,76,0,80,63,0,       0,0,0,0,0,0,0,0,            0,0,0,42,0,39,0,0,
  0,62,0,0,0,0,0,0,         0,0,0,0,0,0,0,0,            0,0,0,0,0,0,0,0,            0,0,0,0,0,0,0,0,
  
  0,0,0,0,0,0,0,0,          0,0,0,0,0,0,0,0,            0,0,0,0,0,64,0,0,           0,0,0,0,0,0,0,0,             // with ALT(GR)
  0,0,0,0,0,0,0,0,          0,0,0,0,0,0,0,0,            0,0,0,0,0,0,0,0,            0,0,0,0,0,123,91,0,
  0,0,0,0,0,125,93,0,       0,0,0,0,0,0,92,0,           0,0,0,0,0,0,0,0,            0,0,0,126,0,0,0,0,
  0,124,0,0,0,0,0,0,        0,0,0,0,0,0,0,0,            0,0,0,0,0,0,0,0,            0,0,0,0,0,0,0,0,
  
  0,0,0,0,0,0,0,0,          0,0,0,0,0,0,0,0,            0,0,0,0,0,0x11,0,0,         0,0,0,0x13,0x01,0,0,0,       // with CTRL(Strg)
  0,0x03,0x18,0,0,0,0,0,    0,0,0x16,0,0,0,0,0,         0,0x0e,0,0,0,0x1a,0,0,      0,0,0,0,0,0,0,0,
  0,0,0,0,0,0,0,0,          0,0,0,0x0c,0,0,0,0,         0,0,0,0,0,0,0,0,            0,0,0,0,0,0,0,0,
  0,0,0,0,0,0,0,0,          0,0,0,0,0,0,0,0,            0,0,0,0,0,0,0,0,            0,0,0,0,0,0,0,0,
*/

// US KEYBOARD LAYOUT (update sections 'PLAIN keys' and 'with SHIFT' for GERMAN KEYBOARD LAYOUT as shown below)

      0,    0,    0,    0,    0,    0,    0,    0,    0,    0,    0,    0,    0, 0x09,    0,    0, // 0x0_ PLAIN keys
      0,    0,    0,    0,    0,  'q',  '1',    0,    0,    0,  'z',  's',  'a',  'w',  '2',    0, // 0x1_
      0,  'c',  'x',  'd',  'e',  '4',  '3',    0,    0,  ' ',  'v',  'f',  't',  'r',  '5',    0, // 0x2_
      0,  'n',  'b',  'h',  'g',  'y',  '6',    0,    0,    0,  'm',  'j',  'u',  '7',  '8',    0, // 0x3_
      0,  ',',  'k',  'i',  'o',  '0',  '9',    0,    0,  '.',  '/',  'l',  ';',  'p',  '-',    0, // 0x4_
      0,    0, '\'',    0,  '[',  '=',    0,    0,    0,    0,   10,  ']',    0, '\\',    0,    0, // 0x5_
      0,  '<',    0,    0,    0,    0,    8,    0,    0, 0xe6,    0, 0xe3, 0xe5,    0,    0,    0, // 0x6_
      0, 0xf0, 0xe2,    0, 0xe4, 0xe1,   27,    0,    0,    0, 0xe8,    0,    0, 0xe7,    0,    0, // 0x7_
// -------------------------------------------------------------------------------------------------------
// 0x_0  0x_1  0x_2  0x_3  0x_4  0x_5  0x_6  0x_7  0x_8  0x_9  0x_a  0x_b  0x_c  0x_d  0x_e  0x_f  // scan code

      0,    0,    0,    0,    0,    0,    0,    0,    0,    0,    0,    0,    0,    0,  '~',    0, // 0x0_ with SHIFT
      0,    0,    0,    0,    0,  'Q',  '!',    0,    0,    0,  'Z',  'S',  'A',  'W',  '@',    0, // 0x1_
      0,  'C',  'X',  'D',  'E',  '$',  '#',    0,    0,    0,  'V',  'F',  'T',  'R',  '%',    0, // 0x2_
      0,  'N',  'B',  'H',  'G',  'Y',  '^',    0,    0,    0,  'M',  'J',  'U',  '&',  '*',    0, // 0x3_
      0,  '<',  'K',  'I',  'O',  ')',  '(',    0,    0,  '>',  '?',  'L',  ':',  'P',  '_',    0, // 0x4_
      0,    0,  '"',    0,  '{',  '+',    0,    0,    0,    0,    0,  '}',    0,  '|',    0,    0, // 0x5_
      0,  '>',    0,    0,    0,    0,    0,    0,    0,    0,    0,    0,    0,    0,    0,    0, // 0x6_
      0,    0,    0,    0,    0,    0,    0,    0,    0,    0,    0,    0,    0,    0,    0,    0, // 0x7_
// -------------------------------------------------------------------------------------------------------
// 0x_0  0x_1  0x_2  0x_3  0x_4  0x_5  0x_6  0x_7  0x_8  0x_9  0x_a  0x_b  0x_c  0x_d  0x_e  0x_f  // scan code

      0,    0,    0,    0,    0,    0,    0,    0,    0,    0,    0,    0,    0,    0,    0,    0, // 0x0_ with ALTGR(=ALT)
      0,    0,    0,    0,    0,  '@',    0,    0,    0,    0,    0,    0,    0,    0,    0,    0, // 0x1_
      0,    0,    0,    0,    0,    0,    0,    0,    0,    0,    0,    0,    0,    0,    0,    0, // 0x2_
      0,    0,    0,    0,    0,    0,    0,    0,    0,    0,    0,    0,    0,  '{',  '[',    0, // 0x3_
      0,    0,    0,    0,    0,  '}',  ']',    0,    0,    0,    0,    0,    0,    0, '\\',    0, // 0x4_
      0,    0,    0,    0,    0,    0,    0,    0,    0,    0,    0,  '~',    0,    0,    0,    0, // 0x5_
      0,  '|',    0,    0,    0,    0,    0,    0,    0,    0,    0,    0,    0,    0,    0,    0, // 0x6_
      0,    0,    0,    0,    0,    0,    0,    0,    0,    0,    0,    0,    0,    0,    0,    0, // 0x7_
// -------------------------------------------------------------------------------------------------------
// 0x_0  0x_1  0x_2  0x_3  0x_4  0x_5  0x_6  0x_7  0x_8  0x_9  0x_a  0x_b  0x_c  0x_d  0x_e  0x_f  // scan code
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

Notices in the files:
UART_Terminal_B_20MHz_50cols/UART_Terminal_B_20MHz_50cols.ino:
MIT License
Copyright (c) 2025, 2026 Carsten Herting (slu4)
